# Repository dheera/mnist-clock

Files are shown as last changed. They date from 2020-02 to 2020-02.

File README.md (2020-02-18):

# MNIST clock

A clock that displays using randomly selected MNIST digits.

Hardware/software implementation by Dheera Venkatraman ([www](http://dheera.net/), [twitter](https://twitter.com/dheeranet))

Original idea/concept by Evan Pu ([www](https://evanthebouncy.github.io), [twitter](https://twitter.com/evanthebouncy))

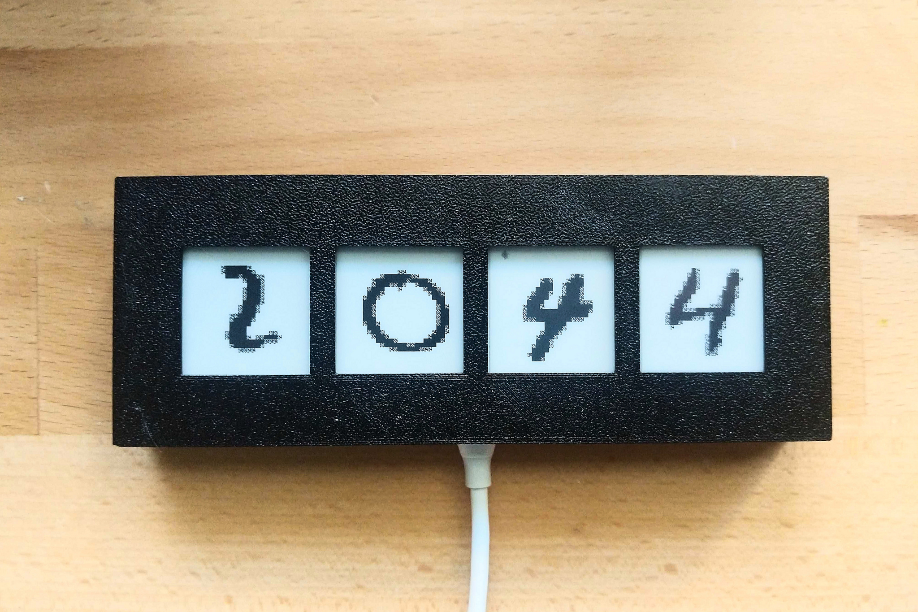
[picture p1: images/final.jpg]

Finished MNIST clock.

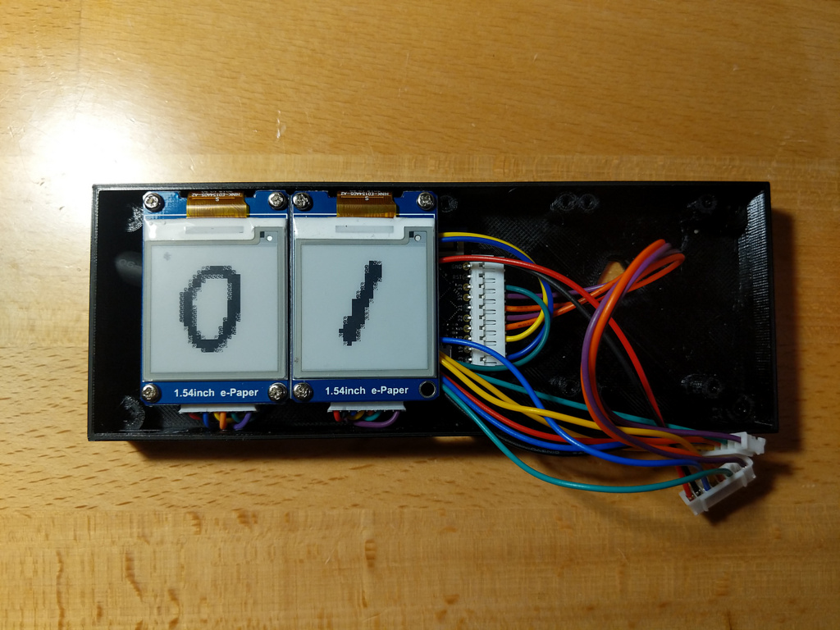
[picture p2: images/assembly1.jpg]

ESP32 and 4 Waveshare e-Ink displays.

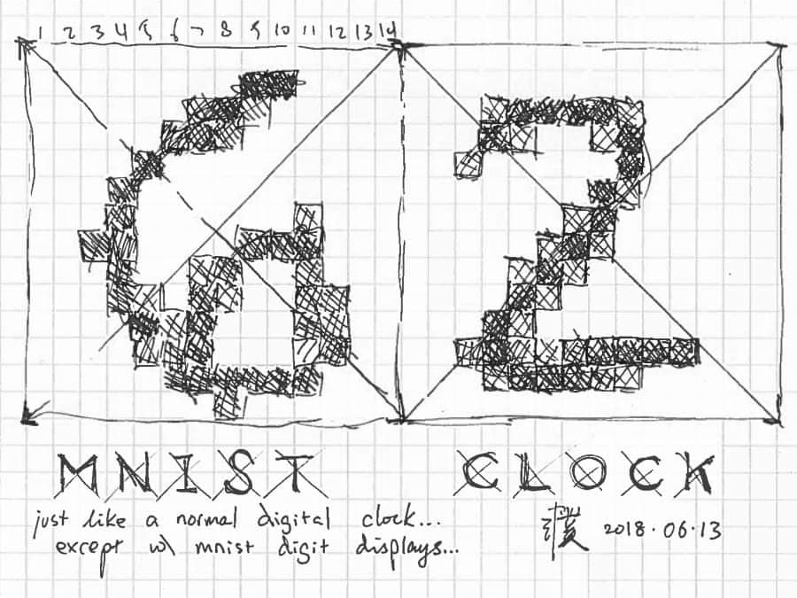
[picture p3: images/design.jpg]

Hand-drawn design by Evan Pu that was posted as a social media status in 2018.

### Original design

### Hardware

It uses an TinyPICO which is an awesome, compact ESP32 board with plenty of GPIO pins, 4MB flash, Wi-Fi, and lots of other features not needed for this project.

4 e-Ink displays are used for the digits. I chose e-Ink since it matches with the idea of handwritten digits, works well in all lighting conditions, and doesn't light up your bedroom when you're trying to sleep. The Waveshare e-Ink displays are mostly SPI, although they have some annoying extra pins. One would wish they were just SPI + one CS pin for each board, but a few more connections are necessary. Here is a diagram of the connections to the ESP32. Crimp the wires according to this.

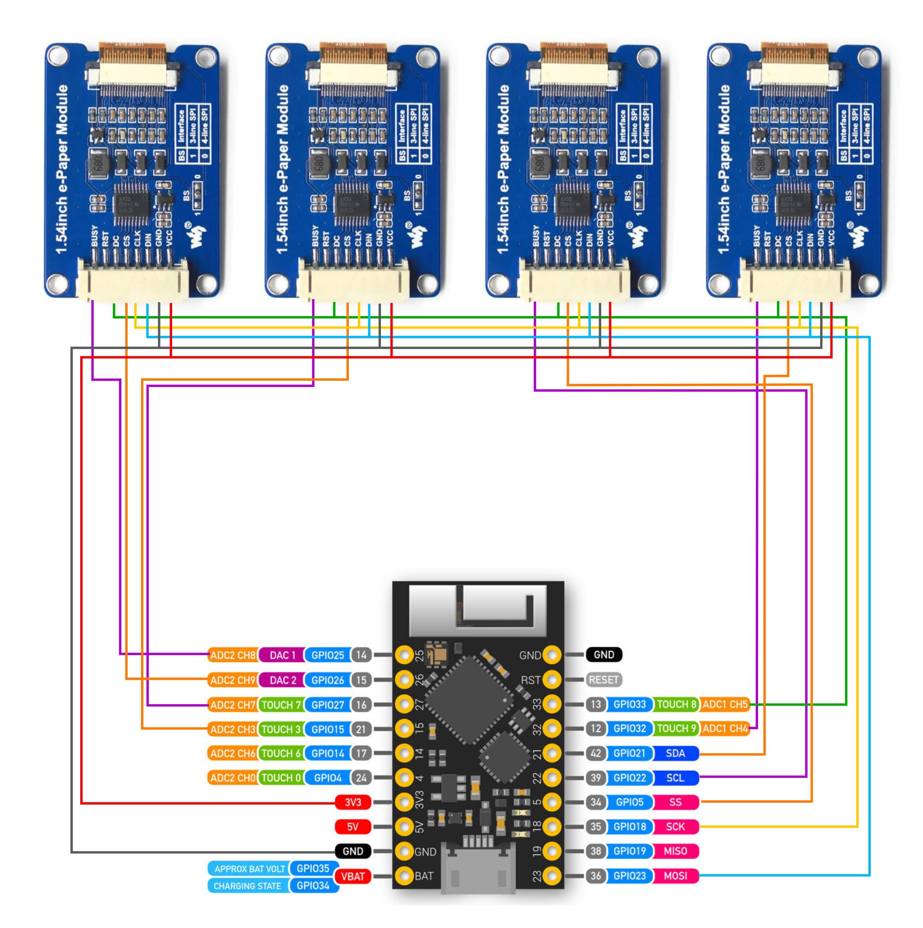
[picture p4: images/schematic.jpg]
schematic


I use 2 10-pin JST-EH connectors on the TinyPICO. JST-EH connectors are awesome, lower profile than JST-XH, more satisfying to plug in than JST-XH, and shorter and more secure than standard pin headers. I use them to connectorize almost all 0.1"/2.5mm pitch breakout boards.

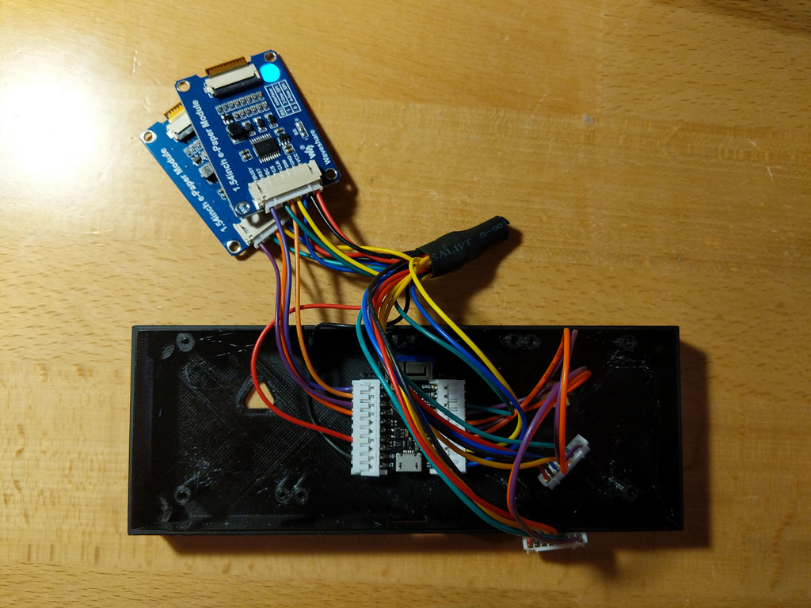
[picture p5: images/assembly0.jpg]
assembly

Connectorized TinyPICO with JST-EH connectors.

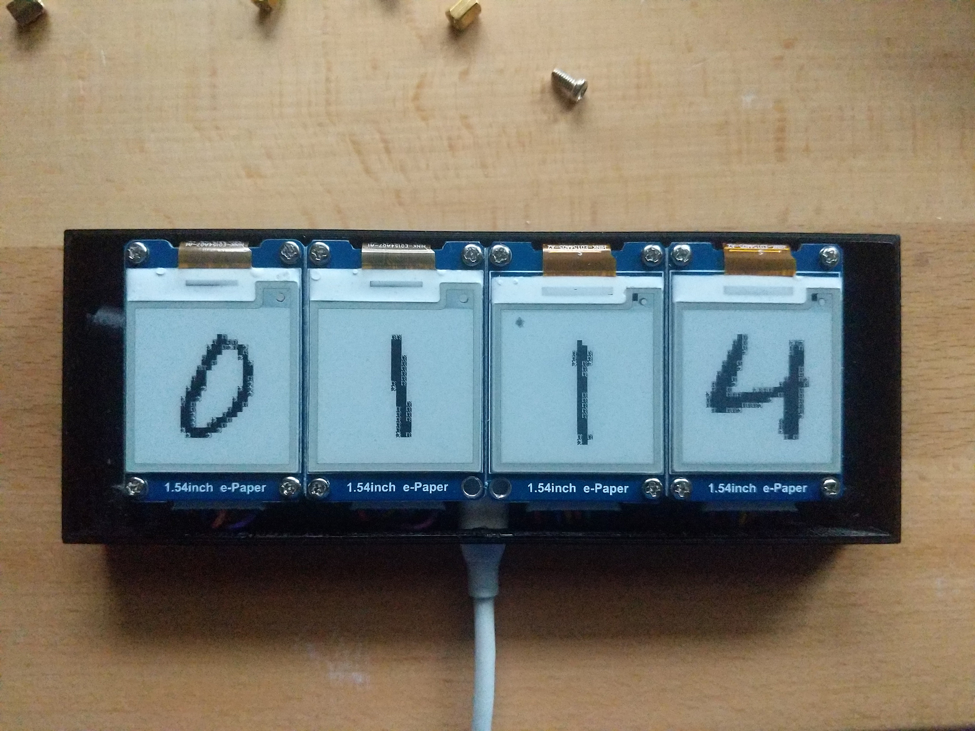
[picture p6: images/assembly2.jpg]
assembly

Displays fixed onto 3D printed housing using self-tapping M2.5 screws.

### Software

I usually write in C++ or C but I was curious about this new MicroPython stuff, so I tried it for this project.

I use 2 bits per pixel of greyscale depth on each MNIST digit (i.e. 4 greyscale levels). At that bit depth, each 28x28 pixel MNIST digit occupies 196 bytes, so 4MB of flash should be able to fit the entire MNIST validation set. If you want to fit more digits you could (a) use a microcontroller board with a lot more flash (b) use 1-bit depth (c) use compression or some combination of the above.

Put all the files in /code in the root directory of your TinyPICO. Also create a file called **.wifi** with you Wi-Fi credentials:
```
yourssid
yourpassword
```

### Parts

#### 3D printed parts

* Bottom and top cover: see .stl files in design/

#### COTS parts

* 4 x [Waveshare 1.54 inch e-Ink display](https://www.amazon.com/Waveshare-Module-Resolution-Electronic-Interface/dp/B0728BJTZC/) -- CAUTION: There are V1, V2, and V2.1 versions of the board that use different communication protocols. Some sellers have mixed-up stockpiles of both versions. You may do best to order 8 or more, pick out 4 identical ones and return the rest. The current state of this repo supports V1 and V2 only. If you get a board that says "Rev 2.1" on it, it will not work.

* 1 x [TinyPICO](https://www.adafruit.com/product/4335)

* 2 x [JST-EH 10-pin right angle header](https://www.digikey.com/products/en/connectors-interconnects/rectangular-connectors-headers-male-pins/314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)

* 2 x [JST-EH 10-pin housing](https://www.digikey.com/products/en/connectors-interconnects/rectangular-connectors-housings/319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)

* 20 x [JST-EH crimps](https://www.digikey.com/product-detail/en/jst-sales-america-inc/SEH-001T-P0.6/455-1042-1-ND/527266)

* 1 x [Anker 6ft white USB-A to USB-Micro-B cable](https://www.amazon.com/Anker-Powerline-Micro-USB-Smartphones/dp/B012VZT5IO/)

* E6000 or similar adhesive to attach the TinyPICO to the case

* [Self tapping M2.5x6 screws](https://www.amazon.com/gp/product/B01L7PDGXO/)

#### Tools

* [PA-09 crimp tool](https://www.amazon.com/Engineers-Precision-Crimping-Pliers-Pa-09/dp/B002AVVO7K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) works for JST-EH

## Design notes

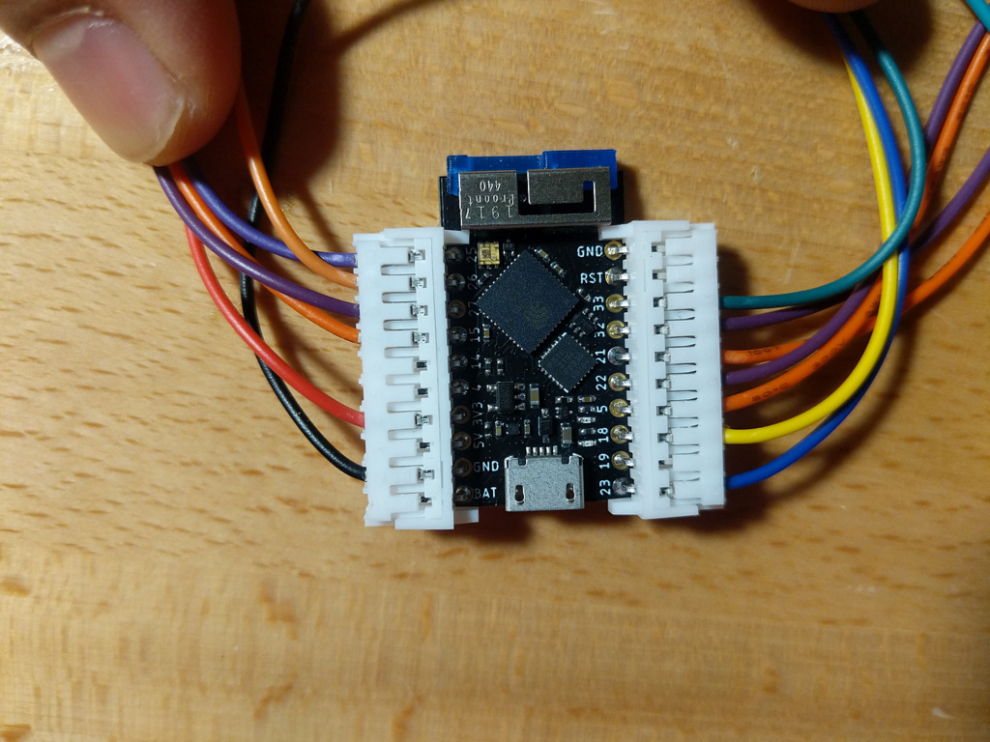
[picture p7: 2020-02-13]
images/tinypico.jpg

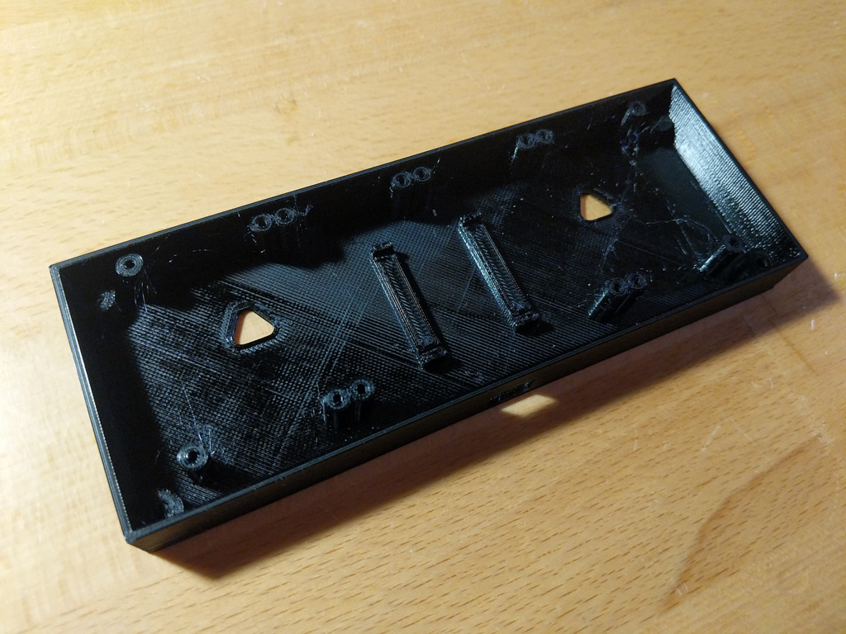
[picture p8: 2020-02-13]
images/case.jpg

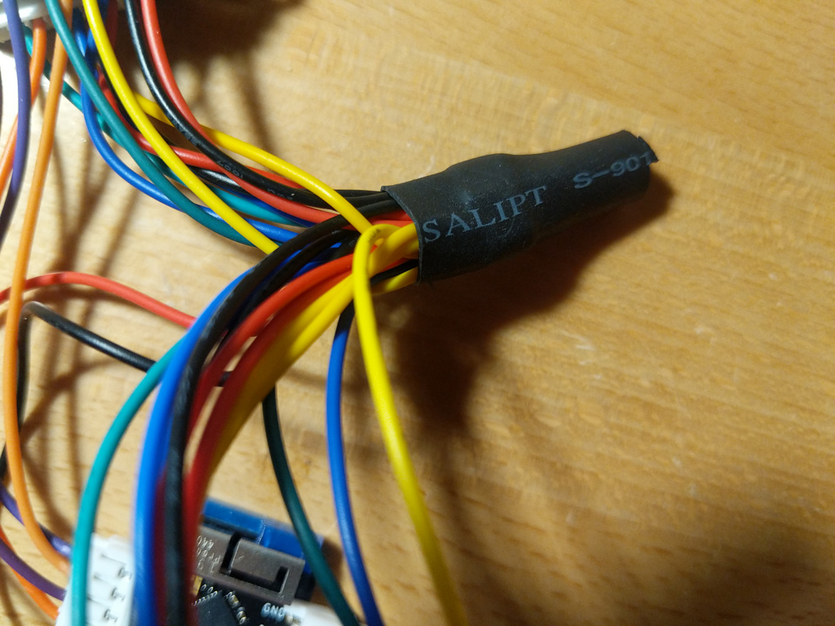
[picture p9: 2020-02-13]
images/wires.jpg

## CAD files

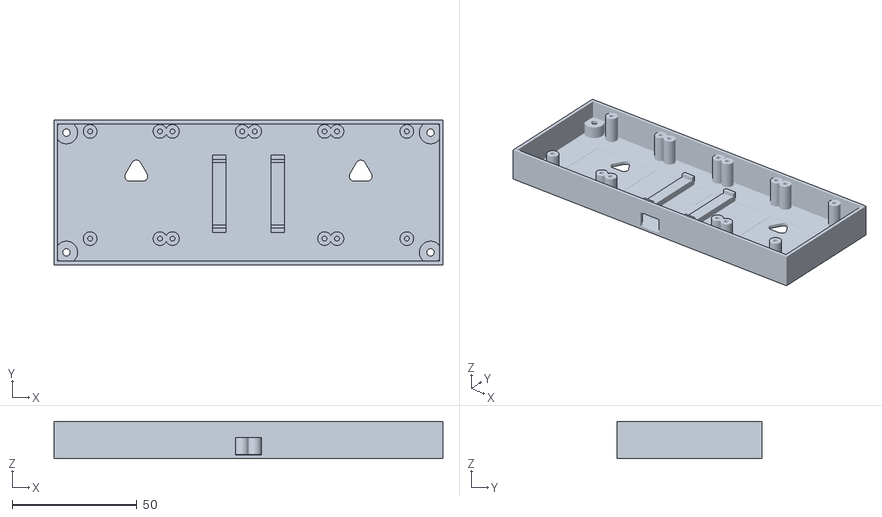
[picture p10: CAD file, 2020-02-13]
design/nistclock-bottom.stl
156.0 x 58.0 x 15.0

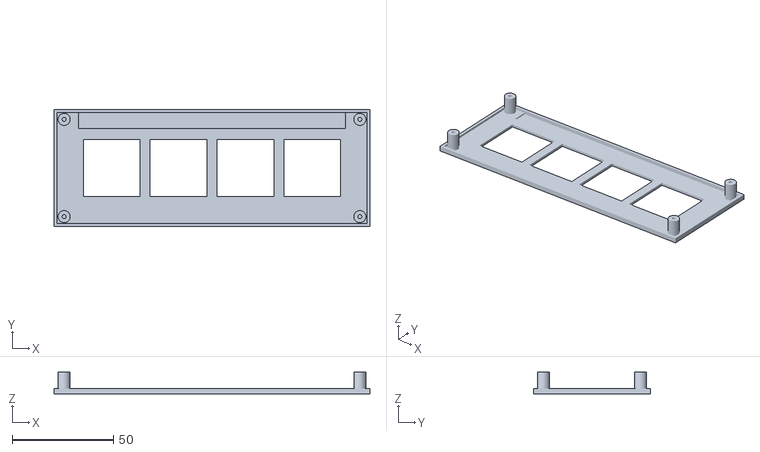
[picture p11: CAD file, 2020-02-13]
design/nistclock-top.stl
156.0 x 58.0 x 10.8

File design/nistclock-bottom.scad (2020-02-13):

L0=33;
L1=24;
L2=4*L0+L1;
W0=48;
W1=10;
W2=W0+W1;
T=1.5;
H=13.5;
offset=3;

difference() {
    cube_center([L2,W2,H+T]);
    
    translate([0,0,1.5])
    cube_center([L2-2*1.5,W2-2*T,25]);
    
    translate([0,-50,1.5])
    usb();
    translate([45,8,0])
    hook();
    translate([-45,8,0])
    hook();
    
    covermountminus();
}

difference() {
    union() {
translate([0,0,T]) {
translate([-L0/2-L0,offset,0])
waveshare();
translate([-L0/2,offset,0])
waveshare();
translate([L0/2,offset,0])
waveshare();
translate([L0/2+L0,offset,0])
waveshare();
}
}
translate([0,-50,0])
cube_center([11,100,100]);
}

translate([0,3.5,T])
tinypico();

translate([0,0,T])
covermount();

module covermount() {
translate([L2/2-5,W2/2-5,0])
standoff(h=H-8,od=9,id=6.5);
    translate([-L2/2+5,-W2/2+5,0])
standoff(h=H-8,od=9,id=6.5);
    translate([-L2/2+5,W2/2-5,0])
standoff(h=H-8,od=9,id=6.5);
    translate([L2/2-5,-W2/2+5,0])
standoff(h=H-8,od=9,id=6.5);
    
translate([L2/2-5,W2/2-5,H-8-1])
standoff(h=1,od=9,id=3);
    translate([-L2/2+5,-W2/2+5,H-8-1])
standoff(h=1,od=9,id=3);
    translate([-L2/2+5,W2/2-5,H-8-1])
standoff(h=1,od=9,id=3);
    translate([L2/2-5,-W2/2+5,H-8-1])
standoff(h=1,od=9,id=3);
}
module covermountminus() {
    translate([L2/2-5,W2/2-5,0])
    standoff(h=H,od=6.5,id=0);
    translate([-L2/2+5,-W2/2+5,0])
standoff(h=H,od=6.5,id=0);
    translate([-L2/2+5,W2/2-5,0])
standoff(h=H,od=6.5,id=0);
    translate([L2/2-5,-W2/2+5,0])
standoff(h=H,od=6.5,id=0);
}

module tinypico() {
    /*difference() {
    cube_center([17.5,33,0.4]);
    }*/
    translate([0,-4,0])
    difference() {
    union() {
    cube_center([29,27.5,2.8]);
    cube_center([29,25,3]);
    }
    cube_center([18,27.5,3]);
    }
    
    translate([0,-4,0])
    difference() {
        cube_center([29,31,4.5]);
        cube_center([29,27.5,6]);
        cube_center([18,33,6]);
    }
    
}


module hook() {
        rotate([0,0,-30])
    minkowski() {
        cylinder(d=6,h=10,$fn=3);
        cylinder(d=4,h=10,$fn=16);
    }
}

module usb() {
    cube_center([10.5,100,7]);
}

module waveshare() {
    difference() {
    cube_center([33,48,0.1]);
        translate([0,-3,0])
        cube_center([28,28,0.1]);
    }
translate([28/2,43/2,0])
standoff();
translate([-28/2,43/2,0])
standoff();
translate([28/2,-43/2,0])
standoff();
translate([-28/2,-43/2,0])
standoff();
}

module standoff(od=5.5,id=2,h=12 ) {
    difference() {
    cylinder(d=od,h=h,$fn=32);
    cylinder(d=id,h=h+0.001,$fn=16);
    }
}
module cube_center(dims) {
  translate([0,0,dims[2]/2])
    cube(dims,center=true);
}

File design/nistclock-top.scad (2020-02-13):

L0=33;
L1=24;
L2=4*L0+L1;
W0=48;
W1=10;
W2=W0+W1;
T=1.5;
H=13.5;
H2=T+1.25;

difference() {
    cube_center([L2,W2,H2]);
    cube_center([L2-2*T,W2-2*T,6]);
}

difference() {
cube_center([L2,W2,1.5]);
    
translate([0,0,0]) {
translate([-L0/2-L0,0,0])
digit();
translate([-L0/2,0,0])
digit();
translate([L0/2,0,0])
digit();
translate([L0/2+L0,0,0])
digit();
}

translate([0,23.5,0.75])
cube_center([L0*4,8,3]);

}

covermount();

module covermount() {
translate([L2/2-5,W2/2-5,0])
standoff(h=H2+8,od=6,id=2);
    translate([-L2/2+5,-W2/2+5,0])
standoff(h=H2+8,od=6,id=2);
    translate([-L2/2+5,W2/2-5,0])
standoff(h=H2+8,od=6,id=2);
    translate([L2/2-5,-W2/2+5,0])
standoff(h=H2+8,od=6,id=2);
}

module digit() {
        translate([0,0,0])
        cube_center([28,28,3]);
}

module standoff(od=5,id=2.5,h=12 ) {
    difference() {
    cylinder(d=od,h=h,$fn=32);
    cylinder(d=id,h=h+0.001,$fn=16);
    }
}
module cube_center(dims) {
  translate([0,0,dims[2]/2])
    cube(dims,center=true);
}

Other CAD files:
design/nistclockcover.scad

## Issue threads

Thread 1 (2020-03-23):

Rev2.1 boards

chrisdearman, 2020-03-23:
You mention in README.md that the Rev2.1 boards do not work.

I've found that the RST pin must be actively driven high. to allow the onboard voltage converter to work. Connecting the displays RST pin to Pin4 allows the code to work without change

dheera, 2020-04-08:
@chrisdearman Oh that's interesting, thanks! I'll dig up a 2.1 board and test that and update within the next couple of days.

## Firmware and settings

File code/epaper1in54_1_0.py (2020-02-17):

"""
MicroPython Waveshare 1.54" Black/White GDEH0154D27 e-paper display driver
https://github.com/mcauser/micropython-waveshare-epaper

MIT License
Copyright (c) 2017 Waveshare
Copyright (c) 2018 Mike Causer

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
from micropython import const
from time import sleep_ms
import ustruct

# Display resolution
EPD_WIDTH  = const(200)
EPD_HEIGHT = const(200)

# Display commands
DRIVER_OUTPUT_CONTROL                = const(0x01)
BOOSTER_SOFT_START_CONTROL           = const(0x0C)
#GATE_SCAN_START_POSITION             = const(0x0F)
DEEP_SLEEP_MODE                      = const(0x10)
DATA_ENTRY_MODE_SETTING              = const(0x11)
#SW_RESET                             = const(0x12)
#TEMPERATURE_SENSOR_CONTROL           = const(0x1A)
MASTER_ACTIVATION                    = const(0x20)
#DISPLAY_UPDATE_CONTROL_1             = const(0x21)
DISPLAY_UPDATE_CONTROL_2             = const(0x22)
WRITE_RAM                            = const(0x24)
WRITE_VCOM_REGISTER                  = const(0x2C)
WRITE_LUT_REGISTER                   = const(0x32)
SET_DUMMY_LINE_PERIOD                = const(0x3A)
SET_GATE_TIME                        = const(0x3B) # not in datasheet
#BORDER_WAVEFORM_CONTROL              = const(0x3C)
SET_RAM_X_ADDRESS_START_END_POSITION = const(0x44)
SET_RAM_Y_ADDRESS_START_END_POSITION = const(0x45)
SET_RAM_X_ADDRESS_COUNTER            = const(0x4E)
SET_RAM_Y_ADDRESS_COUNTER            = const(0x4F)
TERMINATE_FRAME_READ_WRITE           = const(0xFF) # aka NOOP

BUSY = const(1)  # 1=busy, 0=idle

class EPD:
    def __init__(self, spi, cs, dc, rst, busy):
        self.spi = spi
        self.cs = cs
        self.dc = dc
        self.rst = rst
        self.busy = busy
        self.cs.init(self.cs.OUT, value=1)
        self.dc.init(self.dc.OUT, value=0)
        self.rst.init(self.rst.OUT, value=0)
        self.busy.init(self.busy.IN)
        self.width = EPD_WIDTH
        self.height = EPD_HEIGHT

    LUT_FULL_UPDATE    = bytearray(b'\x02\x02\x01\x11\x12\x12\x22\x22\x66\x69\x69\x59\x58\x99\x99\x88\x00\x00\x00\x00\xF8\xB4\x13\x51\x35\x51\x51\x19\x01\x00')
    LUT_PARTIAL_UPDATE = bytearray(b'\x10\x18\x18\x08\x18\x18\x08\x00\x00\x00\x00\x00\x00\x00\x00\x00\x00\x00\x00\x00\x13\x14\x44\x12\x00\x00\x00\x00\x00\x00')

    def _command(self, command, data=None):
        self.dc(0)
        self.cs(0)
        self.spi.write(bytearray([command]))
        self.cs(1)
        if data is not None:
            self._data(data)

    def _data(self, data):
        self.dc(1)
        self.cs(0)
        self.spi.write(data)
        self.cs(1)

    def init(self):
        self.reset()
        self._command(DRIVER_OUTPUT_CONTROL)
        self._data(bytearray([(EPD_HEIGHT - 1) & 0xFF]))
        self._data(bytearray([((EPD_HEIGHT - 1) >> 8) & 0xFF]))
        self._data(bytearray([0x00])) # GD = 0 SM = 0 TB = 0
        self._command(BOOSTER_SOFT_START_CONTROL, b'\xD7\xD6\x9D')
        self._command(WRITE_VCOM_REGISTER, b'\xA8') # VCOM 7C
        self._command(SET_DUMMY_LINE_PERIOD, b'\x1A') # 4 dummy lines per gate
        self._command(SET_GATE_TIME, b'\x08') # 2us per line
        self._command(DATA_ENTRY_MODE_SETTING, b'\x03') # X increment Y increment
        self.set_lut(self.LUT_FULL_UPDATE)

    def wait_until_idle(self):
        while self.busy.value() == BUSY:
            sleep_ms(100)

    def reset(self):
        self.rst(0)
        sleep_ms(200)
        self.rst(1)
        sleep_ms(200)

    def set_lut(self, lut):
        self._command(WRITE_LUT_REGISTER, lut)

    # put an image in the frame memory
    def display(self, image, x = 0, y = 0, w = EPD_WIDTH, h = EPD_HEIGHT):
        # x point must be the multiple of 8 or the last 3 bits will be ignored
        x = x & 0xF8
        w = w & 0xF8

        if (x + w >= self.width):
            x_end = self.width - 1
        else:
            x_end = x + w - 1

        if (y + h >= self.height):
            y_end = self.height - 1
        else:
            y_end = y + h - 1

        self.set_memory_area(x, y, x_end, y_end)
        self.set_memory_pointer(x, y)
        self._command(WRITE_RAM, image)

        self.turn_on_display()

    # replace the frame memory with the specified color
    def clear(self, color):
        self.set_memory_area(0, 0, self.width - 1, self.height - 1)
        self.set_memory_pointer(0, 0)
        self._command(WRITE_RAM)
        # send the color data
        for i in range(0, self.width // 8 * self.height):
            self._data(bytearray([color]))

        self.turn_on_display()

    # draw the current frame memory and switch to the next memory area
    def turn_on_display(self):
        self._command(DISPLAY_UPDATE_CONTROL_2, b'\xC4')
        self._command(MASTER_ACTIVATION)
        self._command(TERMINATE_FRAME_READ_WRITE)
        self.wait_until_idle()

    # specify the memory area for data R/W
    def set_memory_area(self, x_start, y_start, x_end, y_end):
        self._command(SET_RAM_X_ADDRESS_START_END_POSITION)
        # x point must be the multiple of 8 or the last 3 bits will be ignored
        self._data(bytearray([(x_start >> 3) & 0xFF]))
        self._data(bytearray([(x_end >> 3) & 0xFF]))
        self._command(SET_RAM_Y_ADDRESS_START_END_POSITION, ustruct.pack("<HH", y_start, y_end))

    # specify the start point for data R/W
    def set_memory_pointer(self, x, y):
        self._command(SET_RAM_X_ADDRESS_COUNTER)
        # x point must be the multiple of 8 or the last 3 bits will be ignored
        self._data(bytearray([(x >> 3) & 0xFF]))
        self._command(SET_RAM_Y_ADDRESS_COUNTER, ustruct.pack("<H", y))
        self.wait_until_idle()

    # to wake call reset() or init()
    def sleep(self):
        self._command(DEEP_SLEEP_MODE, b'\x01') # enter deep sleep A0=1, A0=0 power on
        self.wait_until_idle()

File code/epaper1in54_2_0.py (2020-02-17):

"""
MicroPython Waveshare 1.54" Black/White GDEH0154D27 e-paper display driver V2

Based on code from
https://github.com/mcauser/micropython-waveshare-epaper
AND
https://github.com/waveshare/e-Paper

MIT License
Copyright (c) 2017 Waveshare
Copyright (c) 2018 Mike Causer
Copyright (c) 2020 Dheera Venkatraman

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
from micropython import const
from time import sleep_ms
import ustruct

# Display resolution
EPD_WIDTH  = const(200)
EPD_HEIGHT = const(200)

BUSY = const(1)  # 1=busy, 0=idle

class EPD:
    def __init__(self, spi, cs, dc, rst, busy):
        self.spi = spi
        self.cs = cs
        self.dc = dc
        self.rst = rst
        self.busy = busy
        self.cs.init(self.cs.OUT, value=1)
        self.dc.init(self.dc.OUT, value=0)
        self.rst.init(self.rst.OUT, value=0)
        self.busy.init(self.busy.IN)
        self.width = EPD_WIDTH
        self.height = EPD_HEIGHT
        self.is_power_on = True

    def _command(self, command):
        self.dc(0)
        self.cs(0)
        self.spi.write(bytearray([command]))
        self.cs(1)

    def _data(self, data):
        self.dc(1)
        self.cs(0)
        self.spi.write(bytearray([data]))
        self.cs(1)

    def wait_until_idle(self):
        print("wait_until_idle")
        while self.busy.value() == BUSY:
            sleep_ms(100)
        sleep_ms(10)

    def turn_on_display(self):
        self._command(0x22) # DISPLAY_UPDATE_CONTROL_2
        self._data(0xF7)
        #self._data(0xF4)
        self._command(0x20) # MASTER_ACTIVATION

        self.wait_until_idle()

    def turn_on_display_part(self):
        self._command(0x22) # DISPLAY_UPDATE_CONTROL_2
        self._data(0xFF)
        self._command(0x20) # MASTER_ACTIVATION

        self.wait_until_idle()


    def init(self):
        print("init")
        self.reset()

        self.wait_until_idle()
        self._command(0x12) # SWRESET
        self.wait_until_idle()

        self._command(0x01) # DRIVER_OUTPUT_CONTROL
        self._data(0xC7) # (EPD_HEIGHT-1) & 0xFF
        self._data(0x00) # ((EPD_HEIGHT-1) >> 8) & 0xFF
        #self._data(0x01) # GD=0 SM=0 TB=0
        self._data(0x00) # GD=0 SM=0 TB=0

        self._command(0x11) # data entry mode
        self._data(0x03)

        self._command(0x44) # set ram-x address start/end position
        self._data(0x00)
        self._data(0x18) # 0x0C --> (18+1)*8 = 200

        self._command(0x45) # set ram-y address start/end position
        self._data(0x00)
        self._data(0x00)
        self._data(0xC7) # 0xC7 --> (199+1) = 200
        self._data(0x00)

        self._command(0x3C) # borderwaveform
        self._data(0x01)

        self._command(0x18)
        self._data(0x80)

        self._command(0x22) # load temperature and waveform setting
        self._data(0xB1)
        self._command(0x20)

        self._command(0x4E) # set RAM x address count to 0
        self._data(0x00)
        self._command(0x4F) # set RAM y address count to 0x199
        self._data(0xC7)
        self._data(0x00)

        # from https://github.com/ZinggJM/GxEPD2/blob/master/src/epd/GxEPD2_154_D67.cpp
        #self._command(0x37)
        #self._data(0x00)
        #self._data(0x00)
        #self._data(0x00)
        #self._data(0x00)
        #self._data(0xff)
        #self._data(0x00)
        #self._data(0x00)
        #self._data(0x00)
        #self._data(0x00)
        #self._data(0x01)

        self.wait_until_idle()

        #self.power_off()

    def reset(self):
        print("reset")
        self.rst(1)
        sleep_ms(100)
        self.rst(0)
        sleep_ms(20)
        self.rst(1)
        sleep_ms(100)

    def clear(self, color):
        # self.power_on()

        self._command(0x24)
        for j in range(0, self.height):
            for i in range(0, int(self.width / 8)):
                self._data(color)
        self.turn_on_display()

        # self.power_off()

    def getbuffer(self, image):
        buf = [0xFF] * (int(self.width/8) * self.height)
        image_monocolor = image.convert('1')
        imwidth, imheight = image_monocolor.size
        pixels = image_monocolor.load()
        if(imwidth == self.width and imheight == self.height):
            logging.debug("Horizontal")
            for y in range(imheight):
                for x in range(imwidth):
                    # Set the bits for the column of pixels at the current position.
                    if pixels[x, y] == 0:
                        buf[int((x + y * self.width) / 8)] &= ~(0x80 >> (x % 8))
        elif(imwidth == self.height and imheight == self.width):
            logging.debug("Vertical")
            for y in range(imheight):
                for x in range(imwidth):
                    newx = y
                    newy = self.height - x - 1
                    if pixels[x, y] == 0:
                        buf[int((newx + newy*self.width) / 8)] &= ~(0x80 >> (y % 8))
        return buf

    def power_off(self):
        # doesn't seem to work, causes updates to fail
        # https://github.com/ZinggJM/GxEPD2/blob/master/src/epd/GxEPD2_154_D67.cpp#L78
        if self.is_power_on:
            self._command(0x22)
            self._data(0x83)
            self._command(0x20)
            sleep_ms(20)
            self.is_power_on = False

    def power_on(self):
        # doesn't seem to work, causes updates to fail
        # https://github.com/ZinggJM/GxEPD2/blob/master/src/epd/GxEPD2_154_D67.cpp#L78
        if not self.is_power_on:
            self._command(0x22)
            self._data(0xF8)
            self._command(0x20)
            self.wait_until_idle()
            self.is_power_on = True

    def display(self, image):
        if (image == None):
            return
        
        #self.power_on()

        self._command(0x24)
        for j in range(0, self.height):
            for i in range(0, int(self.width / 8)):
                self._data(image[i + j * int(self.width / 8)])   
        self.turn_on_display()

        #self.power_off()

    def display_part(self, image):
        if (image == None):
            return
            
        self.send_command(0x24)
        for j in range(0, self.height):
            for i in range(0, int(self.width / 8)):
                self._data(image[i + j * int(self.width / 8)])
                
        self.turn_on_display_part()

    def sleep(self):
        self.send_command(0x10) # DEEP_SLEEP_MODE)
        self.send_data(0x01)

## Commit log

2020-02-13 design files
    [nistclock-bottom.scad, nistclock-bottom.stl, nistclock-top.scad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]
2020-02-17 rm old version of epaper driver; add comment
